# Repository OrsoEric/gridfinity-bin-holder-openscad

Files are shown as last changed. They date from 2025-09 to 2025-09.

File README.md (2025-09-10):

# Gridfinity Bin and Holder OpenSCAD

The scope of this project is to design a stackable gridfinity bin and its holder

## History

Inspiration comes from this design that is very heavy
Design light bins and holders using the gridfinity standard

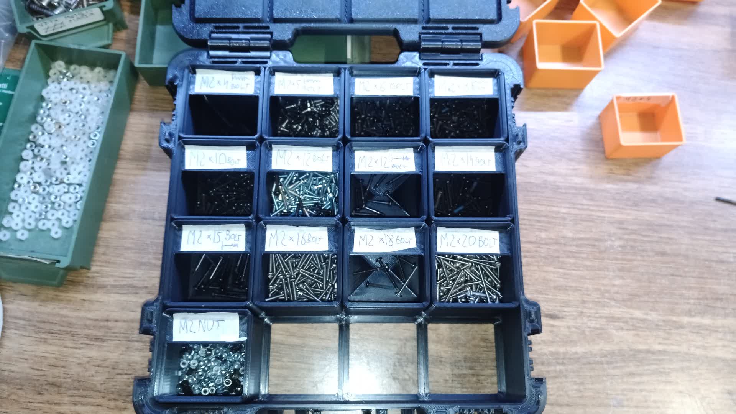
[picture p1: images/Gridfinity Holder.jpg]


[Thingieverse](https://www.printables.com/model/561688-lite-base-for-gridfinity-storage-box-by-pred-now-p/files)

## Improvements

OpenSCAD design

An holder that stacks vertically, so bottom of the holder acts as lid for the holder above.

Snap hinges that are much easier to open

Smaller profile to allow 4x5 printing on a K1 220x220 bed

# Design

## Gridfinity Spec

[Gridfinity Spec](https://gridfinity.xyz/specification/)

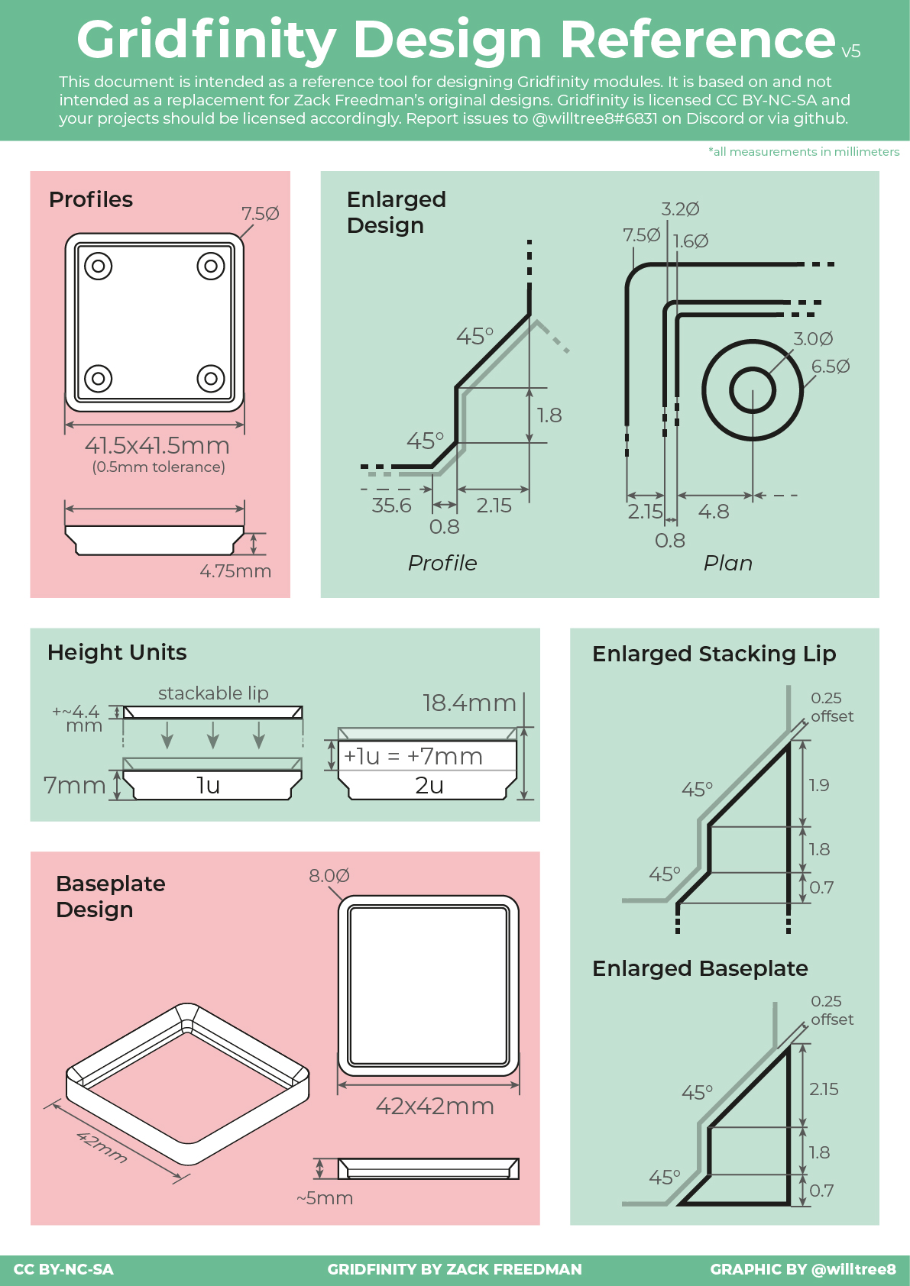
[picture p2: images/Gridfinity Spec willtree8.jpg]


I used a scad gridfinity library for the profile, I found out it's not exactly compliant with Gridfinity spec, one day I'd like to redo it.

## Hinge

The hinge was a sticky part of the design.

I decided to do it vertically, to do a teardrop shape to help with printing, to use the spring action on the side members. It turned out really well and does a satisfying click.

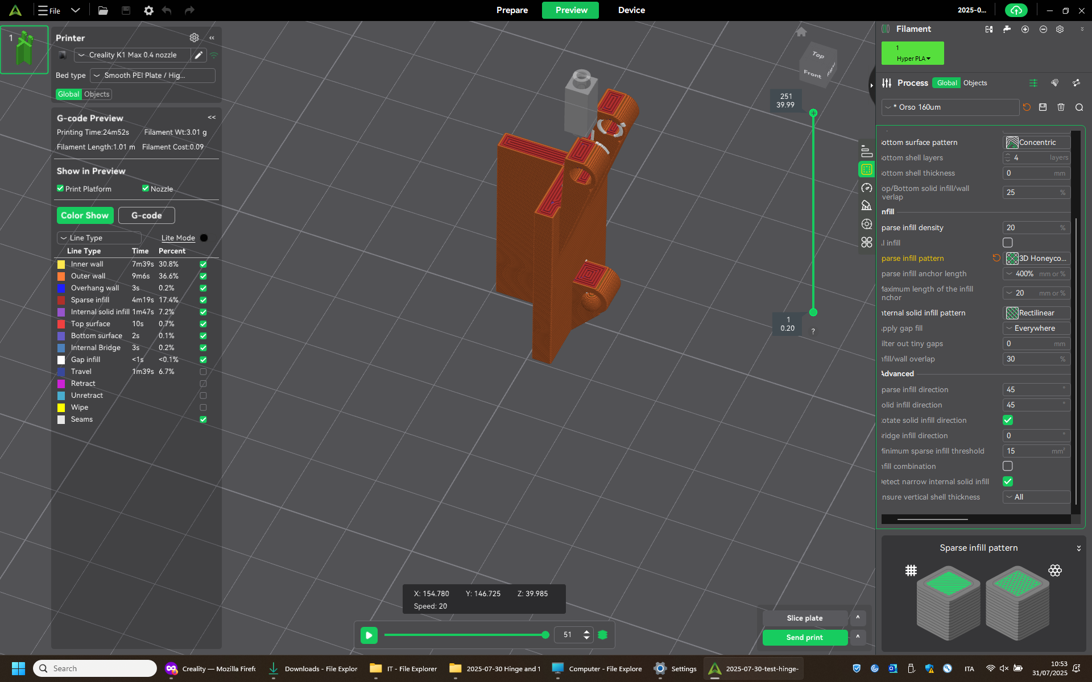
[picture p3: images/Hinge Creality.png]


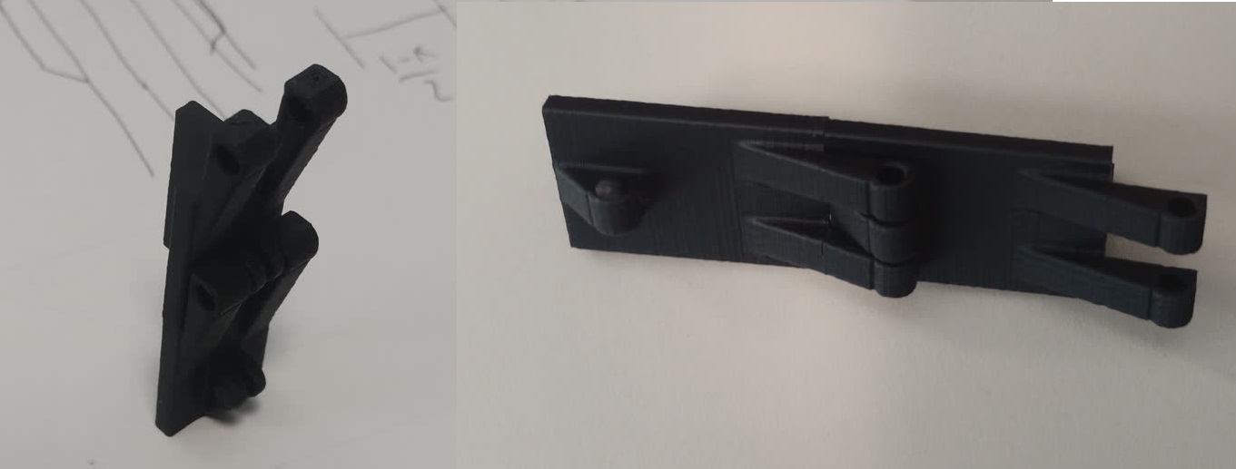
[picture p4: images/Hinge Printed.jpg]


It has a weak point on the side, a future improvement would be tu bury the hinge inside the wall.

## Light Wall

I decided to drill the walls to remove material. After some consideration, I decided for rombus smooth holes in a diagonal grid pattern.

Consideration is to make the rombus taller than they are wide in order to help with overhangs.

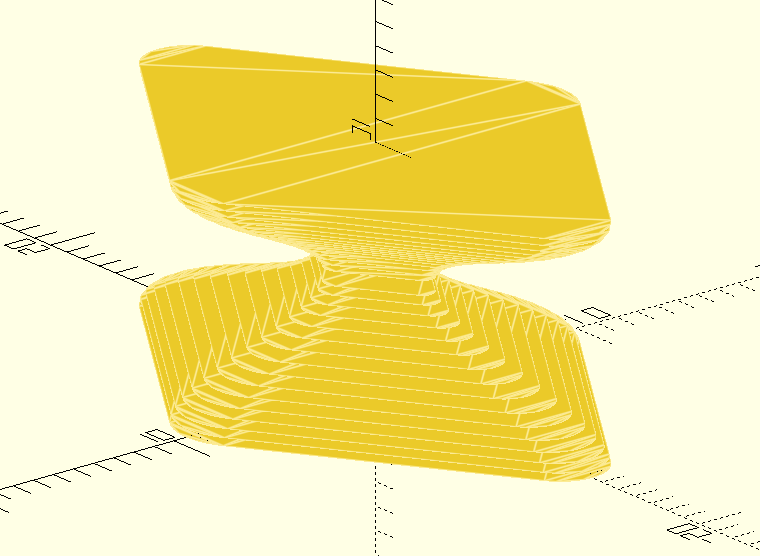
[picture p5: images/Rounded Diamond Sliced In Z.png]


I asked some help on [stack overflow](https://stackoverflow.com/questions/79713218/openscad-concavehull) how to render the smooth rombus because it's concave and doesn't work with hull.

With the diamonds made, I designed the diamond grid pattern.

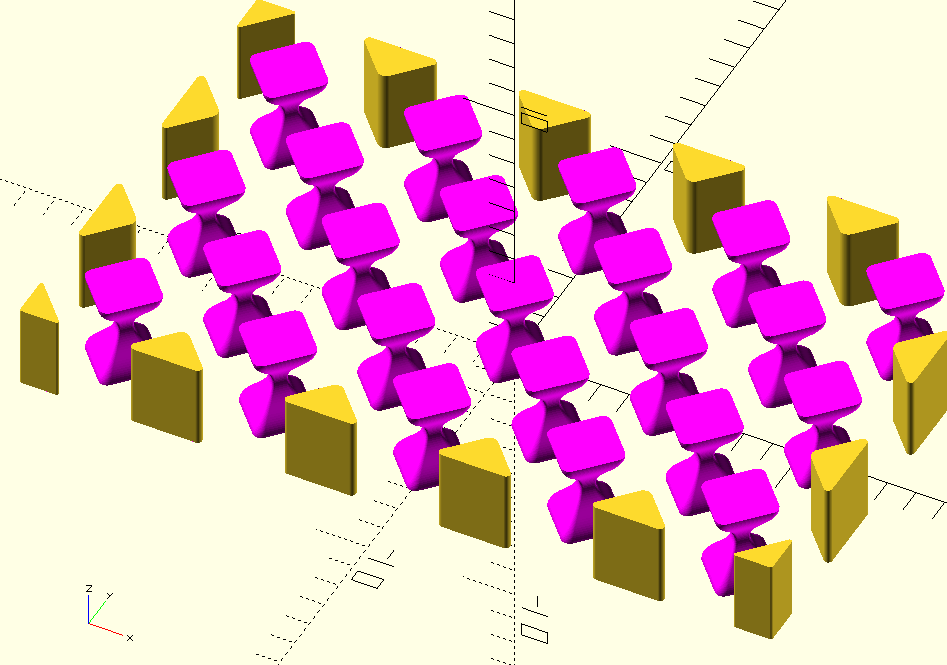
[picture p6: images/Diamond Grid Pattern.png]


From there it's just a matter of extruding that from a regular wall to get a really nice pattern to save on material.

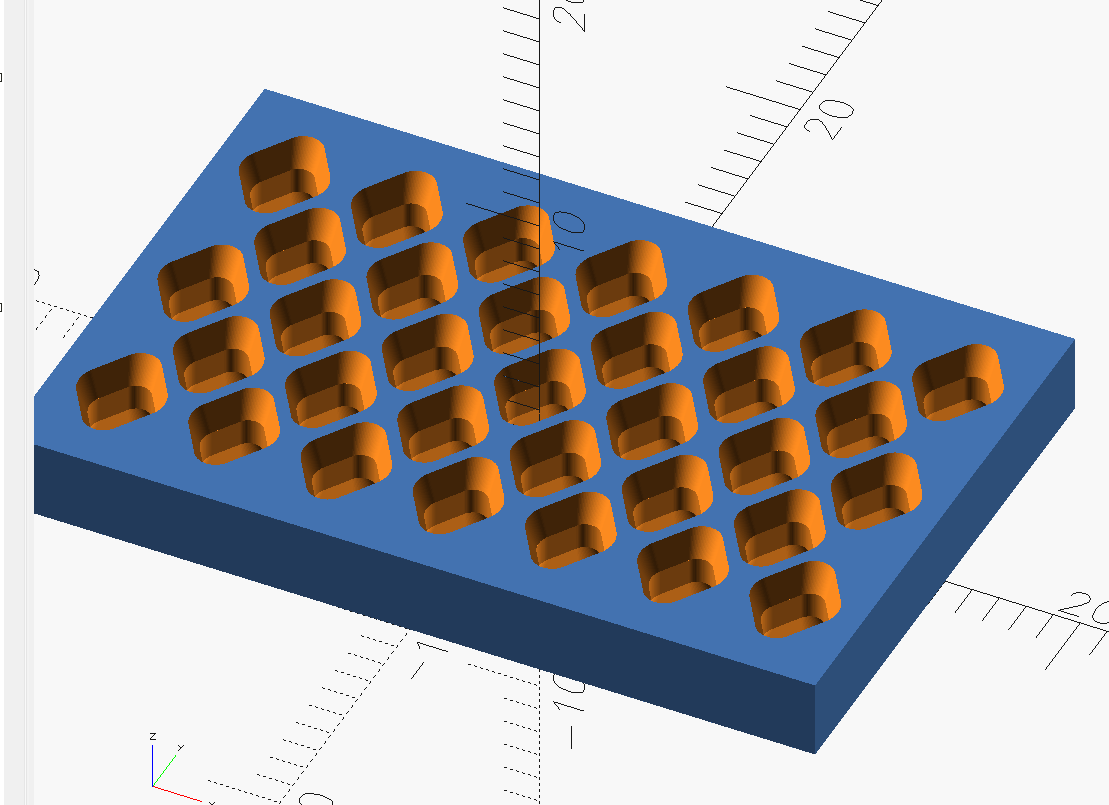
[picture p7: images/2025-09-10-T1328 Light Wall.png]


TODO: I can only handle odd rows because I couldn't be bothered to make the even cutout. In the future I should add the logic to do that, it would make more flexible and scalable the pattern.

## Bin

Making a stackable bin is fairly easy.

It combines a butt, lips for the top, and light walls, all with the proper logic to extend in X and Y direction and get all the roundings and margin right.

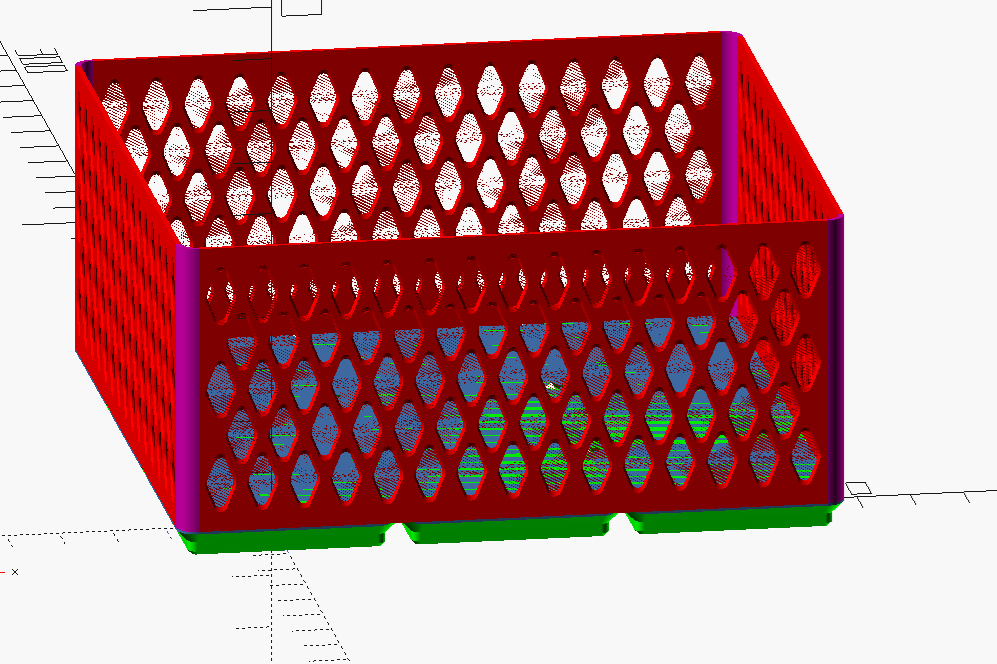
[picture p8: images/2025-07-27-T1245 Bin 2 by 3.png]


I use parameters to decide the number of holes based on bin size and it works fairly well, it's a really nice looking bin with a nice primitive.

## Holder

Making the holder took a lot of effort.

Using the bottom to serve as lid, required working a lot on the geometry to get everything right while keeping everything parametric.

Placing the hinges so that it would close and have good tollerance.

The result is great!

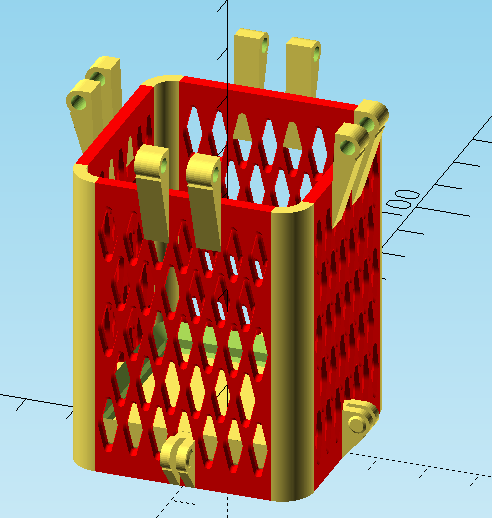
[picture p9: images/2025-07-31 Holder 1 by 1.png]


The black was the first attempt, later I did the white with more spaced holes, tougher hinges and looser tollerance. I ended up doing hinges on just one side since it was good enough and it has great self alignmet.

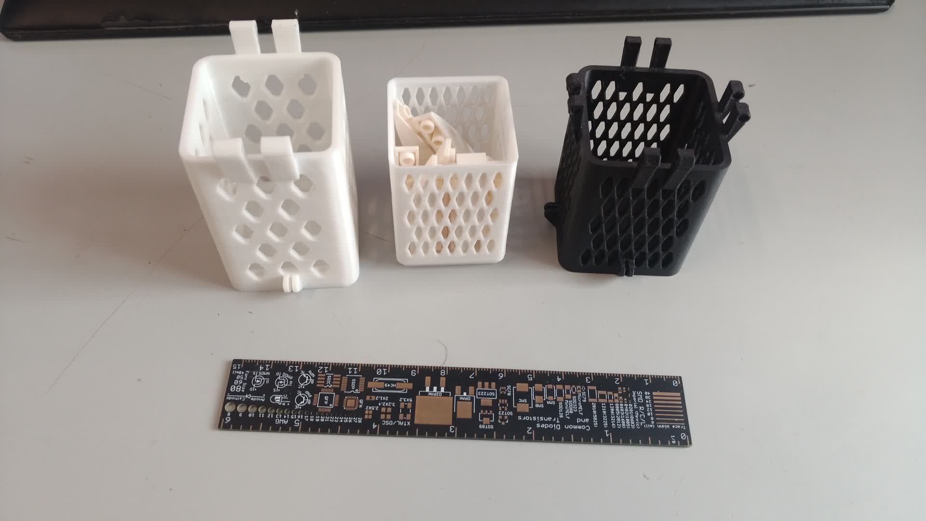
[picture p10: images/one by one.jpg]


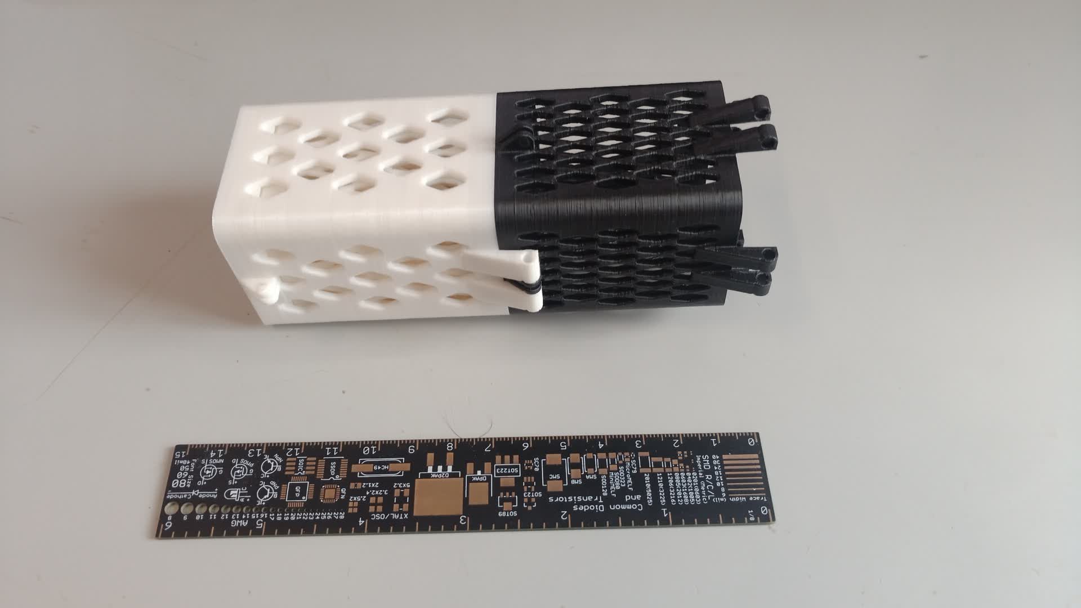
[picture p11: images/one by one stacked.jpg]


It works great on larger sizes

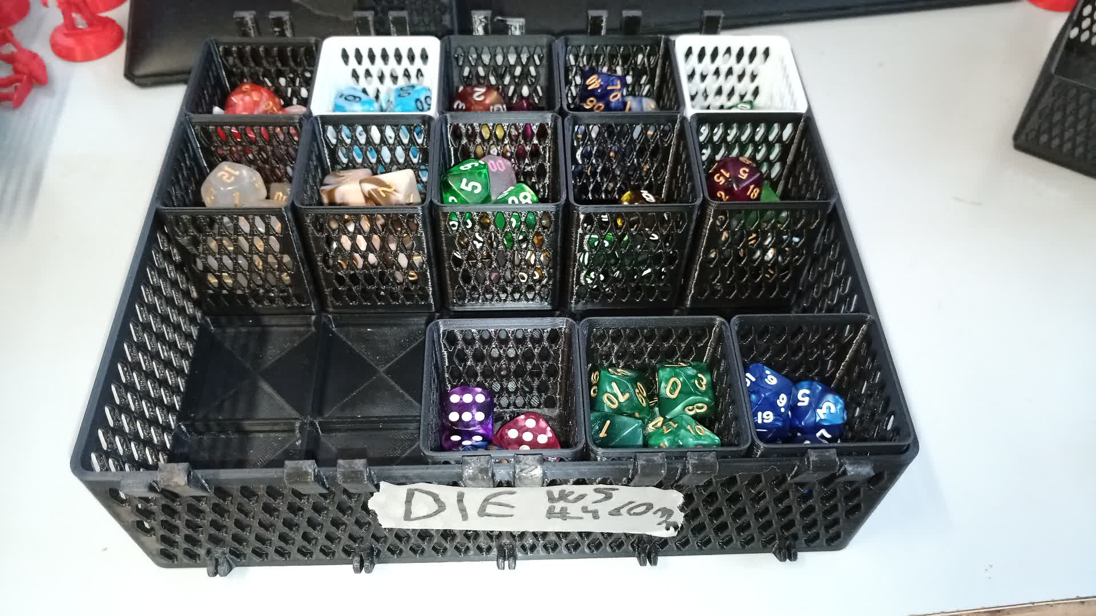
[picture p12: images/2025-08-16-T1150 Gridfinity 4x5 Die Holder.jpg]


It stacks properly and allow me to carry items

## Lid

The lid is an holder with lots of pieces removed.

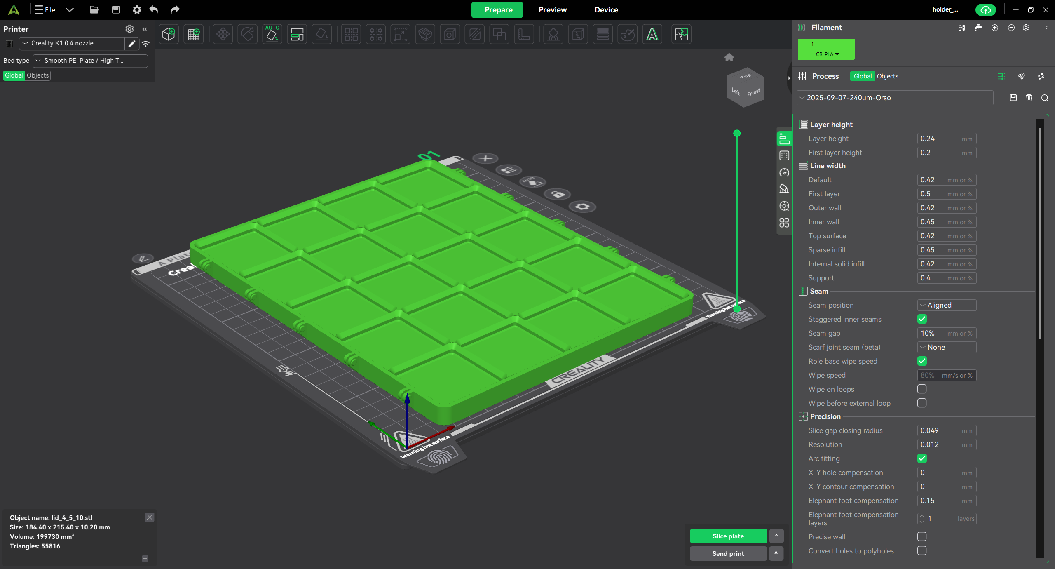
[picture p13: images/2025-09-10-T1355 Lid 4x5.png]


## Handles

I haven't figured out a good way to do handles.

The get to big if I do it in one piece.

I think in the future I'll do an insert to let a handle be screwed in, and make it more convenient to unstuck the holders.

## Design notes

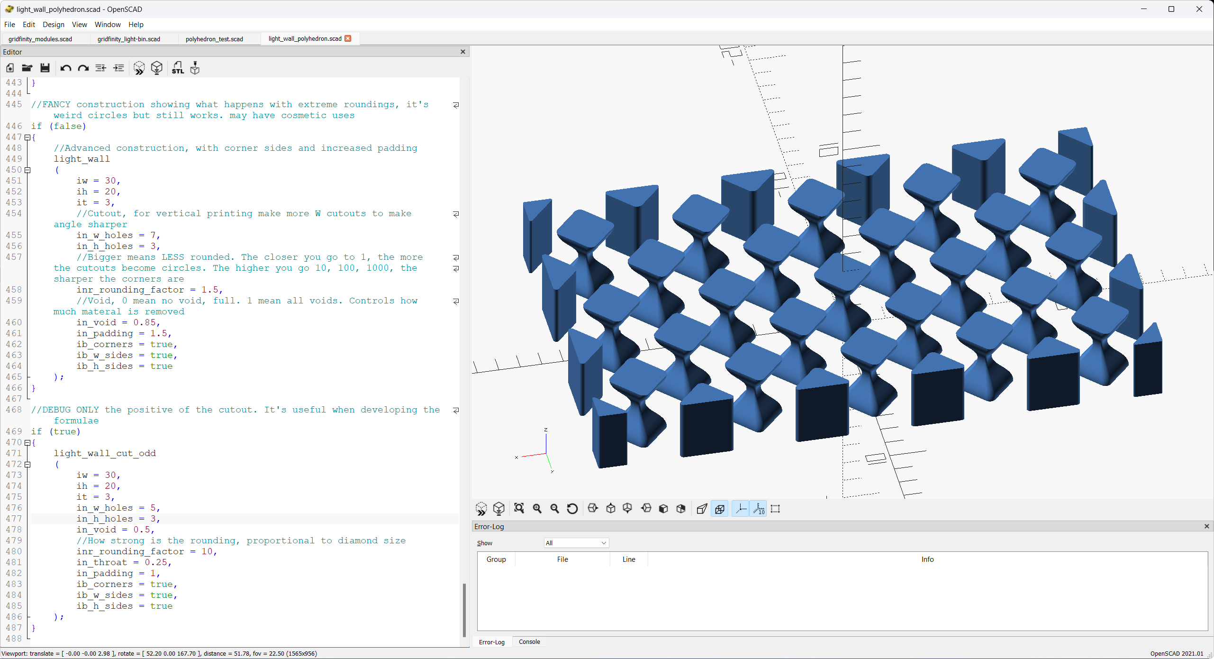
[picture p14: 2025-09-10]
images/Screenshot 2025-07-27 130359.png

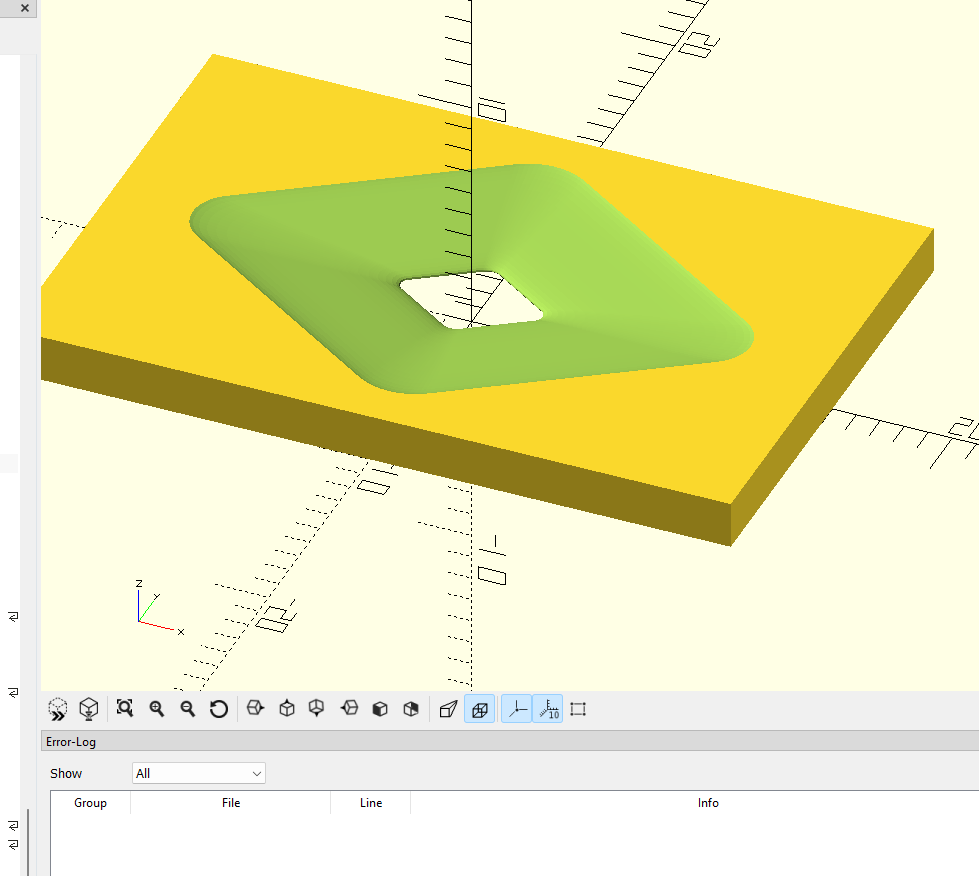
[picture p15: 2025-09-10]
images/Screenshot (21).png

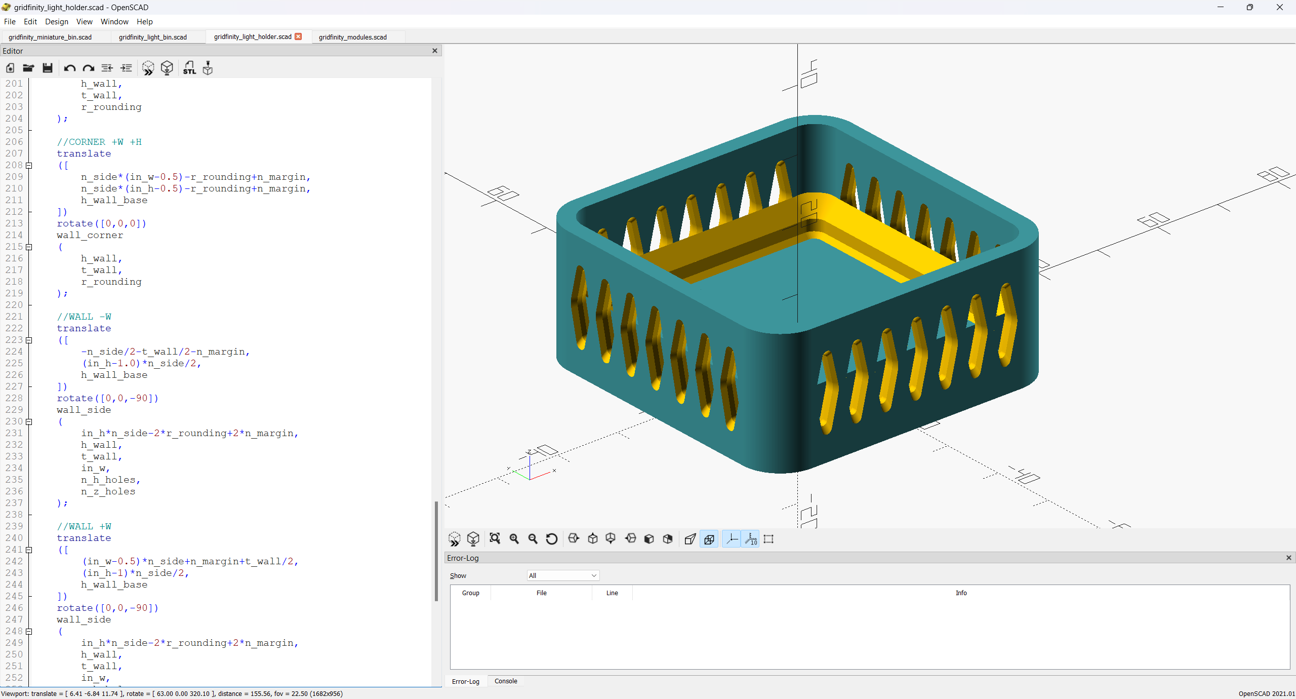
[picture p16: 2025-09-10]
images/Screenshot 2025-07-28 114908.png

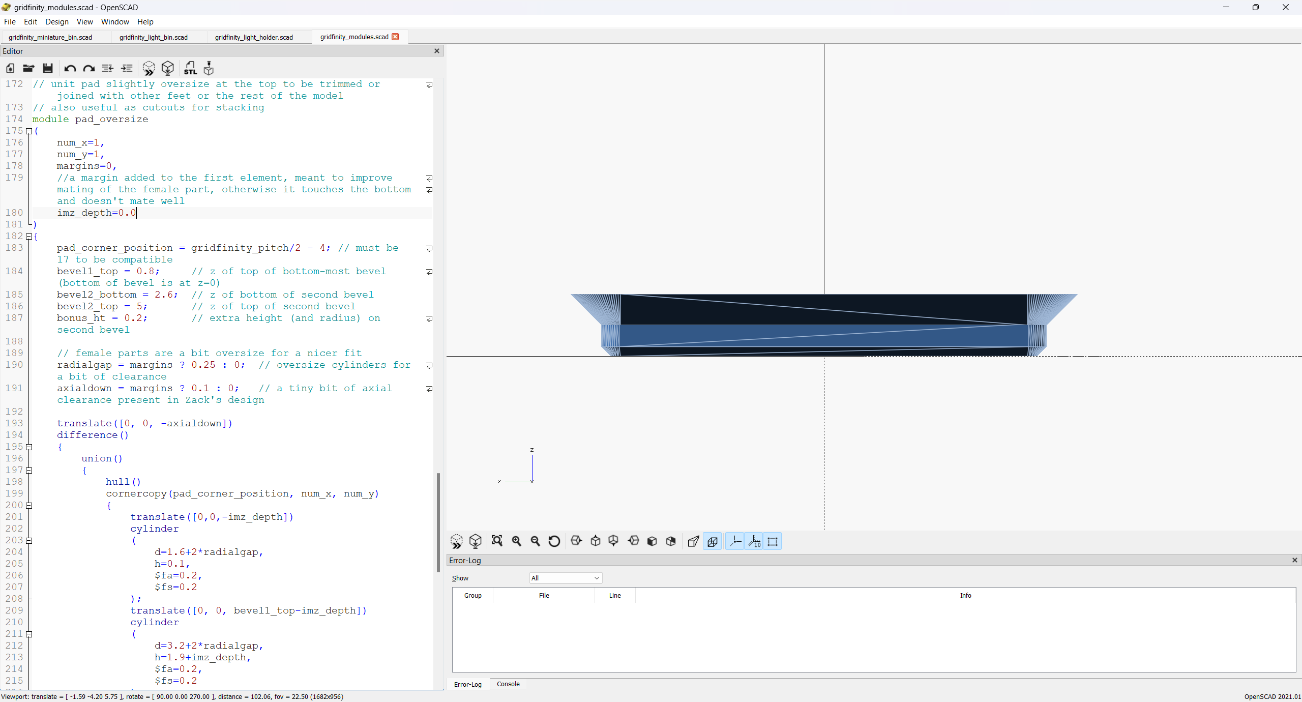
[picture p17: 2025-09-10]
images/Screenshot 2025-07-28 112750.png

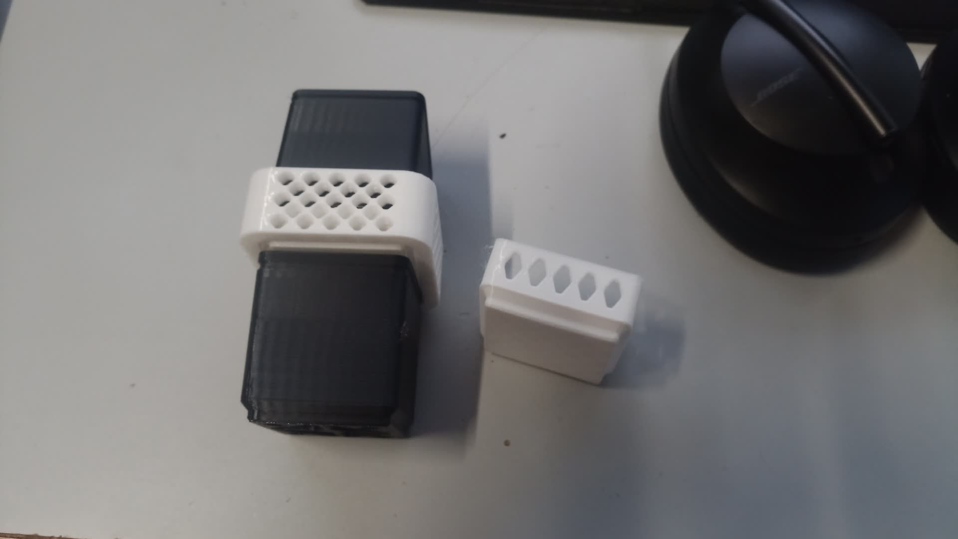
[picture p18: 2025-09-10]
images/2025-07-24_20_56_IMG_20250724_205652.jpg

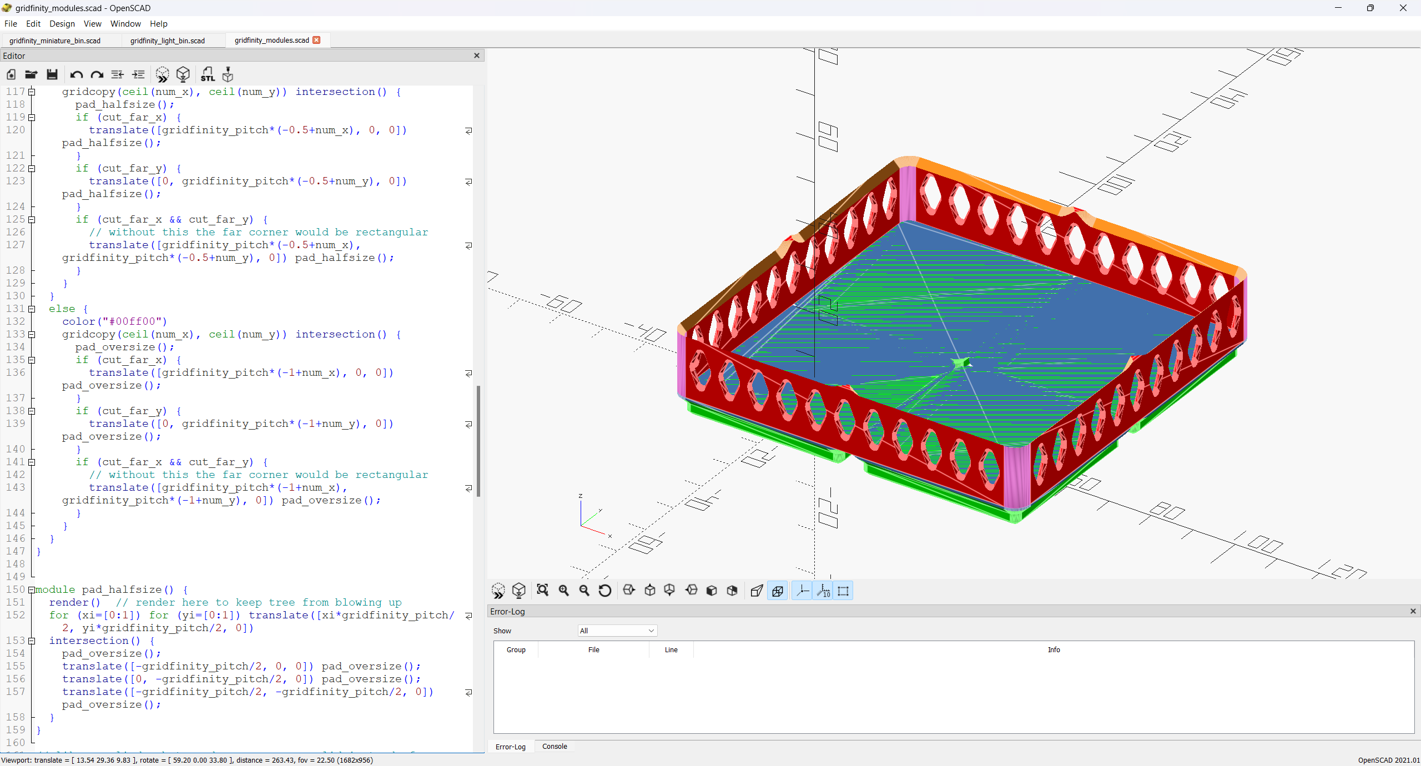
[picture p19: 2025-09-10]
images/Screenshot 2025-07-28 110926.png

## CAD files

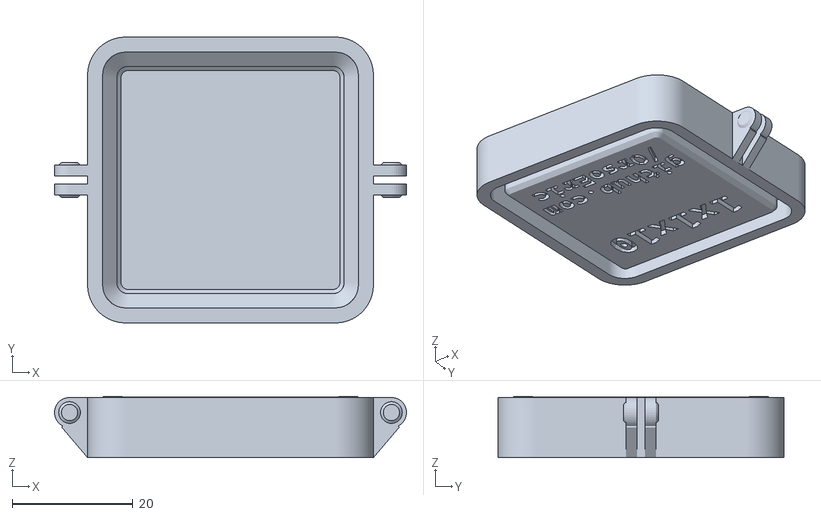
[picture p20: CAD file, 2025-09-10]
stl/lid_1_1_10.stl
58.4 x 47.4 x 10.2

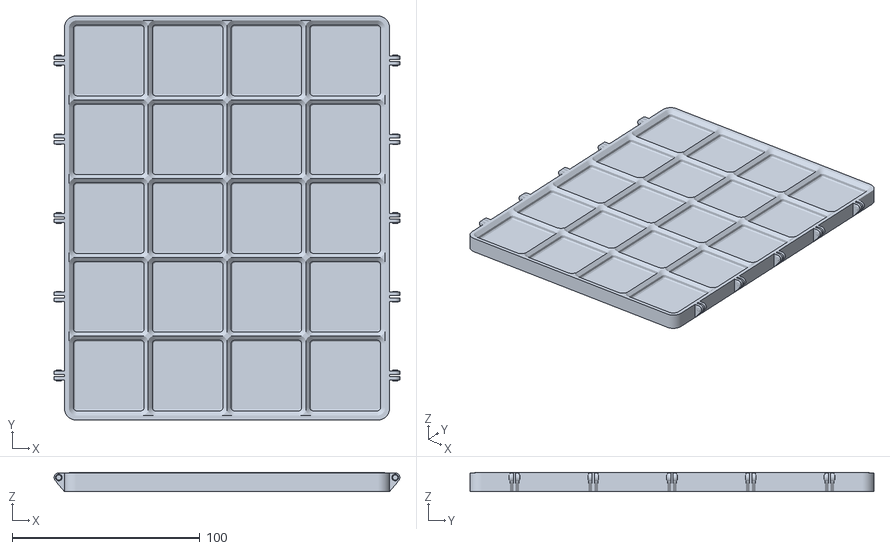
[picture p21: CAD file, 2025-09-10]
stl/lid_4_5_10.stl
184.4 x 215.4 x 10.2

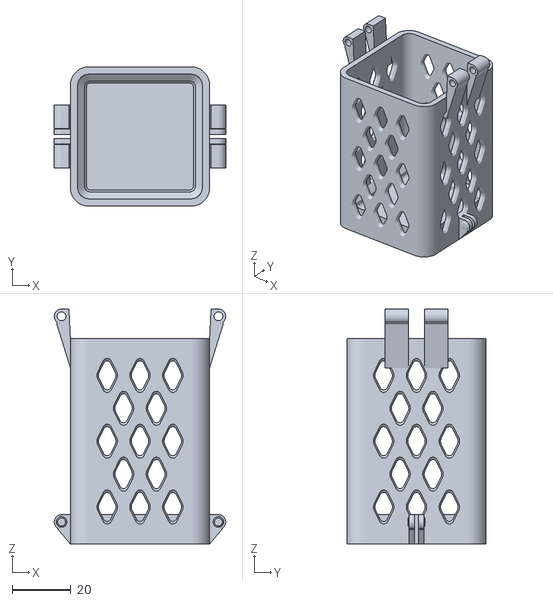
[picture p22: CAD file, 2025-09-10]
stl/holder_1_1_70.stl
58.4 x 47.4 x 80.0

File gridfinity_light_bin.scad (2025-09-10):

//-------------------------------------------------------------------------
//  
//-------------------------------------------------------------------------
// It's the complement of the holder
//Simply the walls are contained inside the tile
//And the top is extruded to be stackable


include <libs/gridfinity_modules.scad>
include <libs/light_wall_zround.scad>
include <libs/lib_text.scad>

module rounded_rectangle
(
	//Number of gridfinity units XY
	in_x,
	in_y,
	in_z,
	//Margin to be eroded from sides
	im_margin=0,
	cp_gridfinity = 42.0,
	ir_rounding = 3.75
	
)
{
	color("#00cccc")
	hull()
	for (n_x=[-0.5,+0.5+(in_x-1)])
	for (n_y=[-0.5,+0.5+(in_y-1)]) 
	{
		translate
		([
			n_x * cp_gridfinity - sign(n_x)*(ir_rounding+im_margin),
			n_y * cp_gridfinity - sign(n_y)*(ir_rounding+im_margin),
			0
		])
		cylinder
		(
			d=ir_rounding,
			h=in_z,
			$fa=1,
			$fs=0.1
		);
	}
}

module base_trimmed
(
	in_w,
	in_h,
	ib_half_pitch = false,
	//Shrinks the sides but NOT the socket, meant for tiling
	im_clearance = 0.5,
	//Curvature radious of the corners
	ir_corners = 3.75,
	//Constant of height from floor to top
	ch_base = 5.2
)
{
	intersection()
	{
		
		// logic for constructing odd-size grids of possibly half-pitch pads
		pad_grid
		(
			in_w,
			in_h,
			ib_half_pitch
		);

		//This builds a smaller block that is intersected to cut the sides for clearance between block, it doesn't alter the male socket
		hull() 
		cornercopy
		(
			gridfinity_pitch/2 - im_clearance/2 - ir_corners,
			in_w,
			in_h
		) 
		cylinder(r=ir_corners, h=ch_base, $fa=0.2,$fs=0.2);
	}

}

module frame_plain
(
    num_x,
    num_y,
    extra_down=0,
    trim=0.0,
    //Mating margin of the base
    im_mate = 1.0
)
{
    corner_radius = 3.75;
    corner_position = gridfinity_pitch/2-corner_radius-trim;
    difference()
    {
        hull()
        cornercopy(corner_position, num_x, num_y) 
        translate([0, 0, -extra_down])
        cylinder(r=corner_radius, h=5.0+extra_down, $fa=0.1, $fs=0.1);
        
        //I'm subtracting a larger bottom to create the socket
        //translate([0, 0, trim ? 0 : -0.01])
        gridcopy(num_x, num_y)
        pad_oversize(margins=im_mate);
    }
}

module wall_corner
(
    //Height of the wall
    ih,
    //Thickness of the wall
    it,
    //Inner curvature radious
    ir
)
{
	color("#cc00aa")
    rotate_extrude(angle=90, $fa=0.2,$fs=0.2)
    polygon([
        [ir+0,0],
        [ir+0,ih],
        [ir+it,ih],
        [ir+it,0]
    ]);   
}

if (false)
wall_corner(100,10,10);

module wall_side
(
    //Width of the wall
    iw,
    //Height of the wall
    ih,
    //Thickness of the wall
    it,
    //Number of gridfinity sides
    in,
	//Number of holes horizontal and vertical, MUST be ODD
	in_w_holes = 1,
	in_h_holes = 1,
	in_void = 0.8,
	in_hole_throat = 0.85
)
{
    //Advanced construction, with corner sides and increased padding
    translate
	([
		0.0,
		it/2,
		ih/2
	])
    rotate([90,0,0])
	color("#ff0000")
    light_wall
    (
        iw = iw,
        ih = ih,
        it = it,
        //Cutout, for vertical printing make more W cutouts to make angle sharper
        in_w_holes = 1+2*in_w_holes,
        in_h_holes = in_h_holes,
        //Bigger means LESS rounded. The closer you go to 1, the more the cutouts become circles. The higher you go 10, 100, 1000, the sharper the corners are
        inr_rounding_factor = 5,
        //Void, 0 mean no void, full. 1 mean all voids. Controls how much materal is removed
        in_void = in_void,
        in_throat = in_hole_throat
    ); 
}

//wall_side(gridfinity_pitch,6,3.75);

module gridfinity_light_bin
(
	in_w,
	in_h,
	//Height of the bin from base to top fo the walls
	iz_top,
	//Thickness of the walls. MUST be smaller than the rounding, it's a different geometry otherwise
	it_wall,
	//Shrinks the sides but NOT the socket, meant for tiling
	im_clearance = 0.5,
	//Curvature radious of the corners
	ir_corners = 3.75,
	//Amount of wall that is void
	in_void = 0.8,
	//Throat of the holes in the wall
	in_hole_throat = 0.8,
	//Constant of height from floor to top of the tile
	h_wall_base = 5.2,
	//How bigger is the female compared to the male for mating, this excrude a socket on the top of the wall for vertical stacking of gridfinity bins
	m_gridfinity_female = 1.0,
	//Each of this height will spawn an additional vertical hole in the wall. Discretized to ODD.
	cz_mm_per_hole = 30,
	//Each of this side length will spawn an horizontal hole. Discretized to ODD.
	cl_mm_per_hole = 15,
	//true: extrude label on the bottom of the bin
	i_x_label = true
)
{
    //Base of the gridfinity plate. Act as lid for the level below
    //pad_oversize(in_w, in_h,margins=0);
    //Put a skinni gridfinity frame above
    //translate([0,0,h_base])
    //frame_plain(in_w, in_h, trim=-0.2);  
    
    n_translate = +gridfinity_pitch/2+0.2;
    n_side = gridfinity_pitch+0.0;
    
	//Margin for  extrusion of the female socket
	czm_female = 0.15;

	//WIP The number of vertical holes scales with height and is then turned into an odd number

	//Turn the number to ODD
	n_z_holes = 1 +2*floor(iz_top/cz_mm_per_hole/2);

	n_w_holes = 1 +2*floor(in_w*gridfinity_pitch/cl_mm_per_hole/2);
	n_h_holes = 1 +2*floor(in_h*gridfinity_pitch/cl_mm_per_hole/2);

	difference()
	{
		union()
		{
			base_trimmed
			(
				//Number of discrete bins
				in_w,
				in_h,
				//???
				ib_half_pitch = false,
				//Shrinks the sides but NOT the socket, meant for tiling
				im_clearance = im_clearance,
				//Curvature radious of the corners
				ir_corners = ir_corners,
				//Constant of height from floor to top of the tile
				ch_base = h_wall_base
			);

			//Make a rounded slab
			translate
			([
				0,
				0,
				5.2
			])
			rounded_rectangle
			(
				in_x = in_w,
				in_y = in_h,
				in_z = 1,
				im_margin = 0.1

			);

			//Put four rounded corner walls 
			//CORNER -W -H, fixed
			translate
			([
				-n_side/2+im_clearance/2 +ir_corners,
				-n_side/2+im_clearance/2 +ir_corners,
				h_wall_base
			])
			rotate([0,0,180])
			wall_corner
			(
				iz_top-h_wall_base,
				it_wall,
				ir_corners -it_wall
			);
			
			//CORNER +W -H
			translate
			([
				n_side*(in_w-0.5)-im_clearance/2 -ir_corners,
				-n_side/2+im_clearance/2 + ir_corners,
				h_wall_base
			])
			rotate([0,0,-90])
			wall_corner
			(
				iz_top-h_wall_base,
				it_wall,
				ir_corners -it_wall
			);
			
			//CORNER -W +H
			translate
			([
				-n_side/2+ir_corners+im_clearance/2,
				n_side*(in_h-0.5)-ir_corners-im_clearance/2,
				h_wall_base
			])
			rotate([0,0,90])
			wall_corner
			(
				iz_top-h_wall_base,
				it_wall,
				ir_corners -it_wall
			);
			
			//CORNER +W +H
			translate
			([
				n_side*(in_w-0.5)-ir_corners-im_clearance/2,
				n_side*(in_h-0.5)-ir_corners-im_clearance/2,
				h_wall_base
			])
			rotate([0,0,0])
			wall_corner
			(
				iz_top-h_wall_base,
				it_wall,
				ir_corners -it_wall
			);
			
			//WALLS
			
			//WALL -W
			translate
			([
				-n_side/2+it_wall/2+im_clearance/2,
				(in_h-1)*n_side/2,
				h_wall_base
			])
			rotate([0,0,-90])
			wall_side
			(
				in_h*n_side-2*ir_corners-im_clearance,
				iz_top-h_wall_base,
				it_wall,
				in_w,
				n_h_holes,
				n_z_holes,
				in_void = in_void,
				in_hole_throat = in_hole_throat
			);
			
			
			//WALL +W
			translate
			([
				(in_w-0.5)*n_side-it_wall/2-im_clearance/2,
				(in_h-1)*n_side/2,
				h_wall_base
			])
			rotate([0,0,90])
			wall_side
			(
				in_h*n_side-2*ir_corners-im_clearance,
				iz_top-h_wall_base,
				it_wall,
				in_w,
				n_h_holes,
				n_z_holes,
				in_void = in_void,
				in_hole_throat = in_hole_throat
				
			);
	
			//WALL -H
			translate([
				(in_w-1.0)*n_side/2-im_clearance*0,
				(-0.5)*n_side+it_wall/2+im_clearance/2,
				h_wall_base
			])
			wall_side
			(
				in_w*n_side-2*ir_corners-im_clearance,
				iz_top-h_wall_base,
				it_wall,
				in_w,
				n_w_holes,
				n_z_holes,
				in_void = in_void,
				in_hole_throat = in_hole_throat
			);
		
			//WALL +H
			translate([
				(in_w-1.0)*n_side/2-im_clearance*0,
				(in_h-0.5)*n_side-it_wall/2-im_clearance/2,
				h_wall_base
			])
			wall_side
			(
				in_w*n_side-2*ir_corners-im_clearance,
				iz_top-h_wall_base,
				it_wall,
				in_w,
				n_w_holes,
				n_z_holes,
				in_void = in_void,
				in_hole_throat = in_hole_throat
			);
			
		} //END UNION POSITIVE
		union()
		{
			translate([
				0,
				0,
				iz_top-h_wall_base+czm_female
			])	
			gridcopy(in_w, in_h)
			//This is the bigger female pad
			pad_oversize(margins=m_gridfinity_female);

			if (i_x_label==true)
			{
				translate([0,gridfinity_pitch/4,0])
				text_line
				(
					i_s_text = str(in_w, "x", in_h, "x", iz_top),
					i_l_text = 6.0,
					i_h_text = 1,
					//Mirror horizontally for bottom extrusion
					i_x_mirror = true
				);
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

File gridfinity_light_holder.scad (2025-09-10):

//-------------------------------------------------------------------------
//  
//-------------------------------------------------------------------------
// It's the complement of the holder
//Simply the walls are contained inside the tile
//And the top is extruded to be stackable


include <libs/gridfinity_modules.scad>
include <libs/light_wall_zround.scad>
//Extrude text at the bottom of the first bin
include <libs/lib_text.scad>

//Defines upper and lower hinge that lock with a sphere and an hole
//The upper hinge needs to be on the low edge
//THe lower hinge needs to be on the upper edge
include <libs/hinge-lock.scad>

//It's 5mm plus 0.2mm margin coming from pad_oversize
h_base = 5.2;
//The height at which walls start
h_wall_base = 0;


t_wall = 2.5;

r_rounding = 3.75;

module frame_plain
(
    num_x,
    num_y,
    extra_down=0,
    trim=0.0,
    //Mating margin of the base
    im_mate = 1.0,
	imz_depth = 0.0
)
{
    corner_radius = 3.75;
    corner_position = gridfinity_pitch/2-corner_radius-trim;
    difference()
    {
        hull()
        cornercopy(corner_position, num_x, num_y) 
        translate([0, 0, -extra_down])
        cylinder(r=corner_radius, h=5.0+extra_down, $fa=0.1, $fs=0.1);
        
        //I'm subtracting a larger bottom to create the socket
        //translate([0, 0, trim ? 0 : -0.01])
        gridcopy(num_x, num_y)
        pad_oversize
		(
			margins=im_mate,
			imz_depth=imz_depth
		);
    }
}

module wall_corner
(
    //Height of the wall
    ih,
    //Thickness of the wall
    it,
    //Inner curvature radious
    ir
)
{
    rotate_extrude(angle=90, $fa=0.2,$fs=0.2)
    polygon([
        [ir+0,0],
        [ir+0,ih],
        [ir+it,ih],
        [ir+it,0]
    ]);   
}

module wall_side
(
    //Width of the wall
    iw,
    //Height of the wall
    ih,
    //Thickness of the wall
    it,
    //Number of gridfinity sides
    in,
	//Number of holes horizontal and vertical, MUST be ODD
	in_w_holes = 1,
	in_h_holes = 1,
	in_void = 0.8,
	in_hole_throat = 0.85
)
{
    //Advanced construction, with corner sides and increased padding
    translate
	([
		0.0,
		it/2,
		ih/2
	])
    rotate([90,0,0])
	color("#ff0000")
    light_wall
    (
        iw = iw,
        ih = ih,
        it = it,
        //Cutout, for vertical printing make more W cutouts to make angle sharper
        in_w_holes = 1+2*in_w_holes,
        in_h_holes = in_h_holes,
        //Bigger means LESS rounded. The closer you go to 1, the more the cutouts become circles. The higher you go 10, 100, 1000, the sharper the corners are
        inr_rounding_factor = 5,
        //Void, 0 mean no void, full. 1 mean all voids. Controls how much materal is removed
        in_void = in_void,
        in_throat = in_hole_throat
    ); 
}

//wall_side(h_wall,t_wall,3.75);

module gridfinity_light_holder
(
	in_w,
	in_h,
	//height of the wall from the floor
	h_wall,
    //??? Does nothing?
	im_mate = 0.0,
    //Extrude more from the female to make male bin mate better with female slot
	imz_female_bottom = 0.2,
	//Each of this height will spawn an additional vertical hole in the wall. Discretized to ODD.
	cz_mm_per_hole = 25,
	//Each of this side length will spawn an horizontal hole. Discretized to ODD.
	cl_mm_per_hole = 15,
	//How much surface voids cover
    in_void = 0.8,
    //Enable spawning of hinge snaps
    ib_hinge_snap = true,
	//Controls how hard are the snap fits
	it_hinge_mate = 0.15,
	it_hinge_interference = 0.225
)
{
	//Turn the number to ODD
	n_z_holes = 1 +2*floor(h_wall/cz_mm_per_hole/2);;
	n_w_holes = 1 +2*floor(in_w*gridfinity_pitch/cl_mm_per_hole/2);
	n_h_holes = 1 +2*floor(in_h*gridfinity_pitch/cl_mm_per_hole/2);
	echo("HOLES | W: ", n_w_holes, " | H: ", n_h_holes, " | Z: ", n_z_holes);

	difference()
	{
		//Base of the gridfinity plate. Act as lid for the level below
		gridcopy(in_w, in_h)
		pad_oversize
		(
			1,
			1,
			margins=im_mate
		);
		union()
		{
			translate([0,gridfinity_pitch/4,0])
			text_line
			(
				i_s_text = str(in_w, "x", in_h, "x", h_wall),
				i_l_text = 6.0,
				i_h_text = 1,
				//Mirror horizontally for bottom extrusion
				i_x_mirror = true
			);

			translate([0,-gridfinity_pitch/4,0])
			text_lines
			(
				i_as_text = 
				[							
					str("github.com"),
					str("/OrsoEric")
				],
				i_l_text = 4,
				i_h_text = 1,
				// Margin between lines
				i_m_line = 1,
				//Mirror horizontally for bottom extrusion
				i_x_mirror = true
			);


		}

	}
    //Put a skinni gridfinity frame above
    translate([0,0,h_base+imz_female_bottom])
    frame_plain
	(
		in_w,
		in_h,
		trim=-0.2,
		//Makes the female bottom deeper to mate better with the male gridfinity on top of it
		imz_depth = imz_female_bottom
	);  
    
    n_translate = +gridfinity_pitch/2+0.2;
    n_side = gridfinity_pitch+0.0;
    
    //There is a non scalable margin that is added only 1X
    n_margin = 0.2;
    
	//-------------------------------------------------------------------------
    //  CORNERS
    //-------------------------------------------------------------------------

    //Put four rounded corner walls 
    //CORNER -W -H, fixed
    translate
	([
		-n_side/2-n_margin+r_rounding,
		-n_side/2-n_margin+r_rounding,
		h_wall_base
	])
    rotate([0,0,180])
    wall_corner
	(
		h_wall,
		t_wall,
		r_rounding
	);
    
    //CORNER +W -H
    translate
	([
		n_side*(in_w-0.5)+n_margin -r_rounding,
		-n_side/2-n_margin + r_rounding,
		h_wall_base
	])
    rotate([0,0,-90])
    wall_corner
	(
		h_wall,
		t_wall,
		r_rounding
	);
    
    //CORNER -W +H
    translate
	([
		-n_side/2+r_rounding-n_margin,
		n_side*(in_h-0.5)-r_rounding+n_margin,
		h_wall_base
	])
    rotate([0,0,90])
    wall_corner
	(
		h_wall,
		t_wall,
		r_rounding
	);
	
	//CORNER +W +H
    translate
	([
		n_side*(in_w-0.5)-r_rounding+n_margin,
		n_side*(in_h-0.5)-r_rounding+n_margin,
		h_wall_base
	])
    rotate([0,0,0])
    wall_corner
	(
		h_wall,
		t_wall,
		r_rounding
	);

	//-------------------------------------------------------------------------
    //  WALLS
    //-------------------------------------------------------------------------
    
    //WALL -W
    translate
	([
		-n_side/2-t_wall/2-n_margin,
		(in_h-1.0)*n_side/2,
		h_wall_base
	])
    rotate([0,0,-90])
    wall_side
	(
		in_h*n_side-2*r_rounding+2*n_margin,
		h_wall,
		t_wall,
		in_w,
		n_h_holes,
		n_z_holes,
		in_void = in_void
	);
    
	//WALL +W
    translate
	([
		(in_w-0.5)*n_side+n_margin+t_wall/2,
		(in_h-1)*n_side/2,
		h_wall_base
	])
    rotate([0,0,-90])
    wall_side
	(
		in_h*n_side-2*r_rounding+2*n_margin,
		h_wall,
		t_wall,
		in_w,
		n_h_holes,
		n_z_holes,
		in_void = in_void
	);
    
    //WALL -H
    translate
	([
		(in_w-1)*n_side/2,
		-n_side/2-t_wall/2-n_margin,
		h_wall_base
	])
    wall_side
	(
		in_w*n_side-2*r_rounding+2*n_margin,
		h_wall,
		t_wall,
		in_w,
		n_w_holes,
		n_z_holes,
		in_void = in_void
	);

	//WALL +H
    translate([
		(in_w-1)*n_side/2,
		(in_h-0.5)*n_side+t_wall/2+n_margin,
		h_wall_base
	])
    wall_side
	(
		in_w*n_side-2*r_rounding+2*n_margin,
		h_wall,
		t_wall,
		in_w,
		n_w_holes,
		n_z_holes,
		in_void = in_void
	);
    
	//-------------------------------------------------------------------------
    //  PILLARS
    //-------------------------------------------------------------------------
	// Vertical structural elements to help integrity of the wall

	//How buried is the pillar inside the wall. 1.0 means it's half out and doesn't intrude
	k_pillar_buried_w = 1.0;
	r_pillar_w = t_wall * 1.0;

	k_pillar_buried_h = 0.8;
	r_pillar_h = t_wall * 0.8;

	//-W
	if (in_h > 0)
	for (n_y=[1:in_h-1])
	translate
	([
		n_side*(-0.5)-n_margin-t_wall*k_pillar_buried_w,
		n_side*(n_y-0.5),
		h_wall_base
	])
	color("#440044")
	cylinder
	(
		r=r_pillar_w,
		h=h_wall,
		$fn=30
	);

	//+W
	if (in_h > 0)
	for (n_y=[1:in_h-1])
	translate
	([
		n_side*(in_w-0.5)+n_margin+t_wall*k_pillar_buried_w,
		n_side*(n_y-0.5),
		h_wall_base
	])
	color("#440044")
	cylinder
	(
		r=r_pillar_w,
		h=h_wall,
		$fn=30
	);

	//-H
	if (in_w > 0)
	for (n_x=[1:in_w-1])
	translate
	([
		n_side*(n_x-0.5)+0*r_rounding,
		n_side*(-0.5)-n_margin-t_wall*k_pillar_buried_h,
		h_wall_base
	])
	color("#440044")
	cylinder
	(
		r=r_pillar_h,
		h=h_wall,
		$fn=30
	);

	//+H
	if (in_w > 0)
	for (n_x=[1:in_w-1])
	translate
	([
		n_side*(n_x-0.5)+0*r_rounding,
		n_side*(in_h-0.5)+n_margin+t_wall*k_pillar_buried_h,
		h_wall_base
	])
	color("#440044")
	cylinder
	(
		r=r_pillar_h,
		h=h_wall,
		$fn=30
	);
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

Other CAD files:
gridfinity_light_lid.scad

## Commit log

2025-09-09 Move scad files developed for the DnD miniature holder.
    [gridfinity_light_bin.scad, gridfinity_light_holder.scad]
2025-09-10 move files for holders generate better pillars as they interfered with long bins add library for multiline text add stl for some sizes of bins
    [gridfinity_light_bin.scad, gridfinity_light_holder.scad]
2025-09-10 design lid and make some stl
    [gridfinity_light_lid.scad, holder_1_1_70.stl, lid_1_1_10.stl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]
